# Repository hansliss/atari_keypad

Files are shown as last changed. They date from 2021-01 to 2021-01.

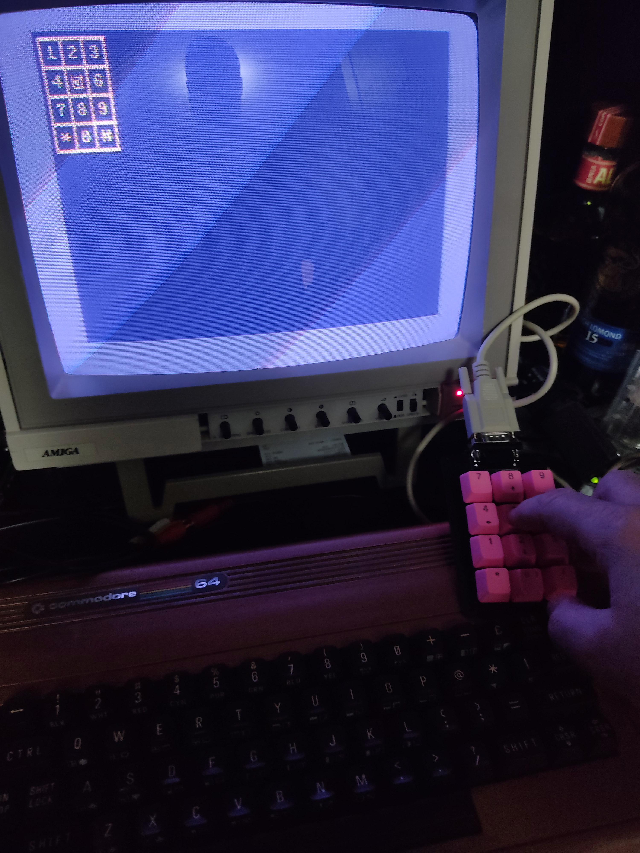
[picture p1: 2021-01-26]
2021-01-25 19.21.43.jpg

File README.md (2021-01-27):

# atari_keypad

A 12-key keypad for the joystick port, based on the Atari 2600 keypad

keypad

The keypad uses Kailh sockets for Cherry MX-compatible keyswitches,
and is meant to be used with a 3d-printed box, including a faceplate
to keep the switches in place. This box has not been designed yet.

keypad bottom

The keypad has anti-ghosting diodes on all keys. There are three
pull-up resistors, one for each column. The original keypad only
included the first two resistors, and as far as I know, the third
one is not needed.

The design includes a PCB-mounted DB-9 female connector. You can use
this with a straight, fully connected DB-9 male-to-female cable to
connect the keypad to a computer or console, or you can just solder
cables to the solder pads if you prefer that.

keypad and VIC

Included is also VIC-20 code for scanning the keypad. It includes
full N-key rollover and produces two bytes of bits, one bit for each
key. Debouncing is done by delaying keypress events until they have
been seen by at least two scanning cycles.

There is a second machine code program that calls the poller and then
"unpacks" the bit fields into a series of individual bytes, one for
each key. This is because BASIC turns out to be breathtakingly slow
at this kind of bit-mangling.

There are two BASIC programs, one that uses just the main subroutine
and does the bit unpacking itself, and another on that uses the "reorg"
subroutine to to get unpacked bytes. The second one is a little bit
faster.

Finally, there is a machine code version of the BASIC code, which
better demonstrates the keypad at full speed.

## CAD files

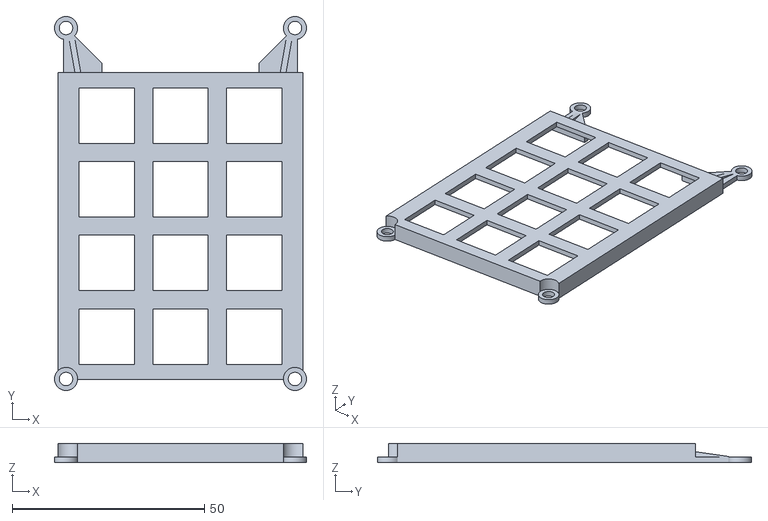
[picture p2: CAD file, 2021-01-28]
faceplate.stl
65.5 x 97.2 x 5.00

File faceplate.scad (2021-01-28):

$fn=256;

switchHoleWidth=14.4;
switchHoleDepth=14.4;
plateThickness=1.5;
facePlateTop=5;

switchesX = 3;
switchesY = 4;

switchDistX=19.15;
switchDistY=19.15;

switchOuterMargin=4;

holeDistXFromSwitchCenter = 9.85;
bottomHoleDistYFromSwitchCenter = 11;
holeYDistance=91.2;

// The keys are, sadly, not exactly centered, but this design is fixed now so we'll compensate instead.
holeRightXPos = 59.5/2; //((switchesX - 1) / 2) * switchDistX + holeDistXFromSwitchCenter;
holeLeftXPos = -holeRightXPos - 0.43;
bottomHoleYPos = -(((switchesY - 1) / 2) * switchDistY + bottomHoleDistYFromSwitchCenter);
topHoleYPos = bottomHoleYPos + holeYDistance;

topEdgeGap=36;

holeDia=3.5;
holeOuterDia=6;

facePlateWidth = (switchesX - 1) * switchDistX + switchHoleWidth + 2 * switchOuterMargin;
facePlateDepth = (switchesY - 1) * switchDistY + switchHoleDepth + 2 * switchOuterMargin;

topEdgePartWidth=(facePlateWidth - topEdgeGap) / 2;

topSparWidth=10;
topSparDepth=holeYDistance - facePlateDepth - holeDia/2;

difference() {
    union() {
        translate([0, 0, facePlateTop - plateThickness/2])
            difference() {
                cube([facePlateWidth, facePlateDepth, plateThickness], center=true);
                union() {
                    for (x = [0 : switchesX - 1]) {
                        for (y = [0 : switchesY - 1]) {
                            translate([x * switchDistX + switchHoleWidth/2 - facePlateWidth/2 + switchOuterMargin,
                                       y * switchDistY + switchHoleDepth/2 - facePlateDepth/2 + switchOuterMargin, 0])
                                cube([switchHoleWidth, switchHoleDepth, plateThickness + 0.02], center=true);
                        }
                    }
                }
            }
        intersection() {
            translate([0, 0, facePlateTop/2])
                cube([facePlateWidth, facePlateDepth, facePlateTop], center=true);
            union() {
                translate([holeLeftXPos, bottomHoleYPos, 0])
                    cylinder(r=holeOuterDia/2 + plateThickness, h=facePlateTop);
                translate([holeRightXPos, bottomHoleYPos, 0])
                    cylinder(r=holeOuterDia/2 + plateThickness, h=facePlateTop);
            }
        }
        translate([0, -(facePlateDepth/2 - plateThickness/2), facePlateTop/2])
            cube([facePlateWidth, plateThickness, facePlateTop], center = true);
        translate([-(facePlateWidth/2 + plateThickness/2), 0, facePlateTop/2])
            cube([plateThickness, facePlateDepth, facePlateTop], center = true);
        translate([(facePlateWidth/2 + plateThickness/2), 0, facePlateTop/2])
            cube([plateThickness, facePlateDepth, facePlateTop], center = true);
        translate([(facePlateWidth/2 - topEdgePartWidth/2), facePlateDepth/2 - plateThickness/2, facePlateTop/2])
            cube([topEdgePartWidth, plateThickness, facePlateTop], center=true);
        translate([-(facePlateWidth/2 - topEdgePartWidth/2), facePlateDepth/2 - plateThickness/2, facePlateTop/2])
            cube([topEdgePartWidth, plateThickness, facePlateTop], center=true);
        translate([(facePlateWidth/2 - topSparWidth/2), facePlateDepth/2 + topSparDepth/2, plateThickness/2])
            union() {
                difference() {
                    cube([topSparWidth, topSparDepth, plateThickness], center=true);
                    translate([-(topSparDepth*0.71 + holeDia), topSparDepth*0.61, 0])
                        rotate([0, 0, 45])
                            cube([topSparDepth*2, topSparDepth*2, plateThickness + 0.02], center=true);
                }
                translate([2, -1, plateThickness/2])
                    rotate([-8, 0, -10])
                        cube([plateThickness, topSparDepth, plateThickness], center=true);
            }
        translate([-(facePlateWidth/2 - topSparWidth/2), facePlateDepth/2 + topSparDepth/2, plateThickness/2])
            union() {
                difference() {
                    cube([topSparWidth, topSparDepth, plateThickness], center=true);
                    translate([topSparDepth*0.71 + holeDia, topSparDepth*0.61, 0])
                        rotate([0, 0, -45])
                            cube([topSparDepth*2, topSparDepth*2, plateThickness + 0.02], center=true);
                }
                translate([-2, -1, plateThickness/2])
                    rotate([-8, 0, 10])
                        cube([plateThickness, topSparDepth, plateThickness], center=true);
            }
    }
    union() {
        translate([holeLeftXPos, bottomHoleYPos, -0.01])
            cylinder(r = holeOuterDia/2, h = facePlateTop + 0.02);
        translate([holeRightXPos, bottomHoleYPos, -0.01])
            cylinder(r = holeOuterDia/2, h = facePlateTop + 0.02);
    }
}

translate([holeLeftXPos, bottomHoleYPos, 0])
    difference() {
        cylinder(r=holeOuterDia/2, h=plateThickness);
        translate([0, 0, -0.01])
            cylinder(r=holeDia/2, h=plateThickness + 0.02);
    }
translate([holeRightXPos, bottomHoleYPos, 0])
    difference() {
        cylinder(r=holeOuterDia/2, h=plateThickness);
        translate([0, 0, -0.01])
            cylinder(r=holeDia/2, h=plateThickness + 0.02);
    }
translate([holeLeftXPos, topHoleYPos, 0])
    difference() {
        cylinder(r=holeOuterDia/2, h=plateThickness);
        translate([0, 0, -0.01])
            cylinder(r=holeDia/2, h=plateThickness + 0.02);
    }
translate([holeRightXPos, topHoleYPos, 0])
    difference() {
        cylinder(r=holeOuterDia/2, h=plateThickness);
        translate([0, 0, -0.01])
            cylinder(r=holeDia/2, h=plateThickness + 0.02);
    }

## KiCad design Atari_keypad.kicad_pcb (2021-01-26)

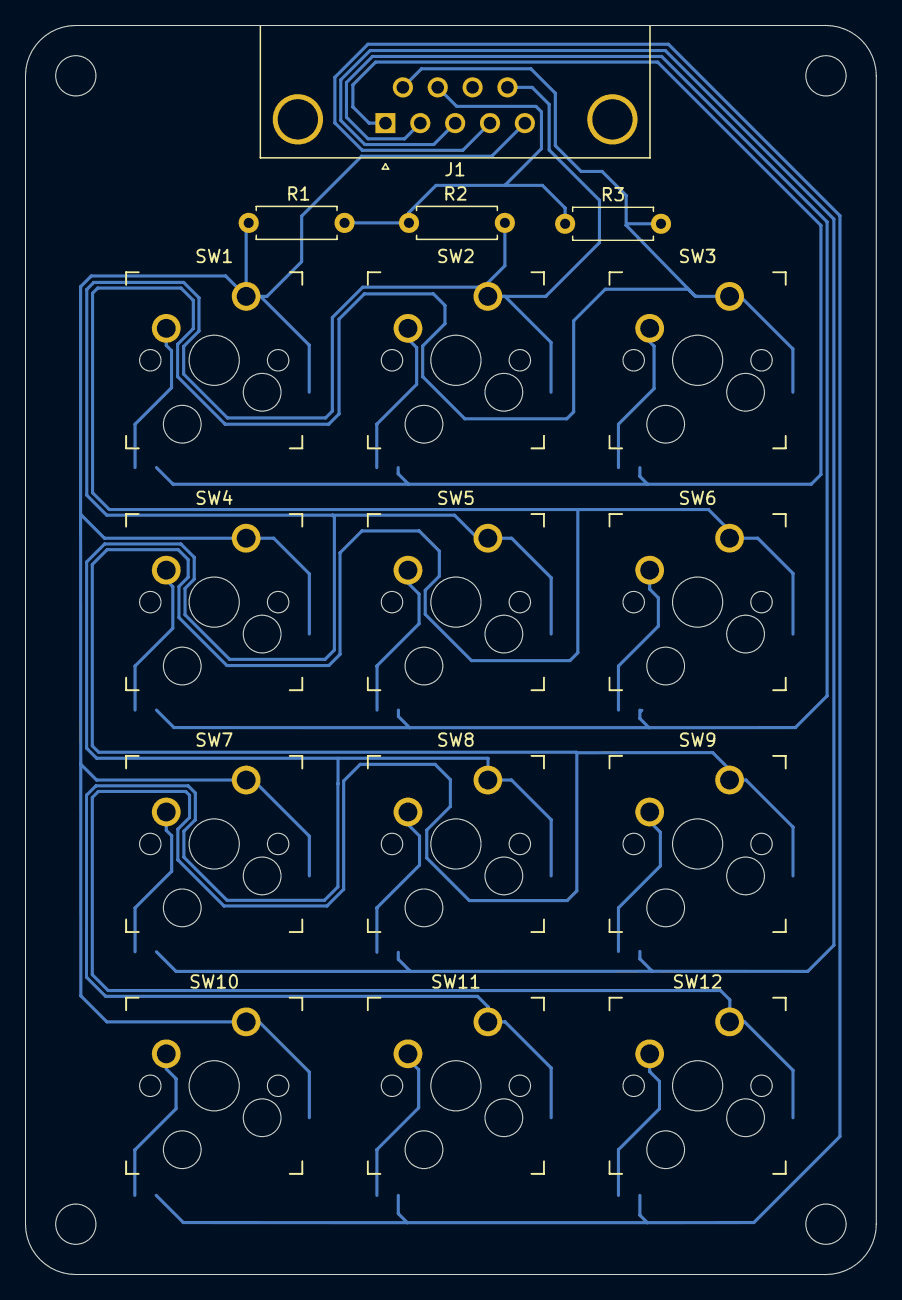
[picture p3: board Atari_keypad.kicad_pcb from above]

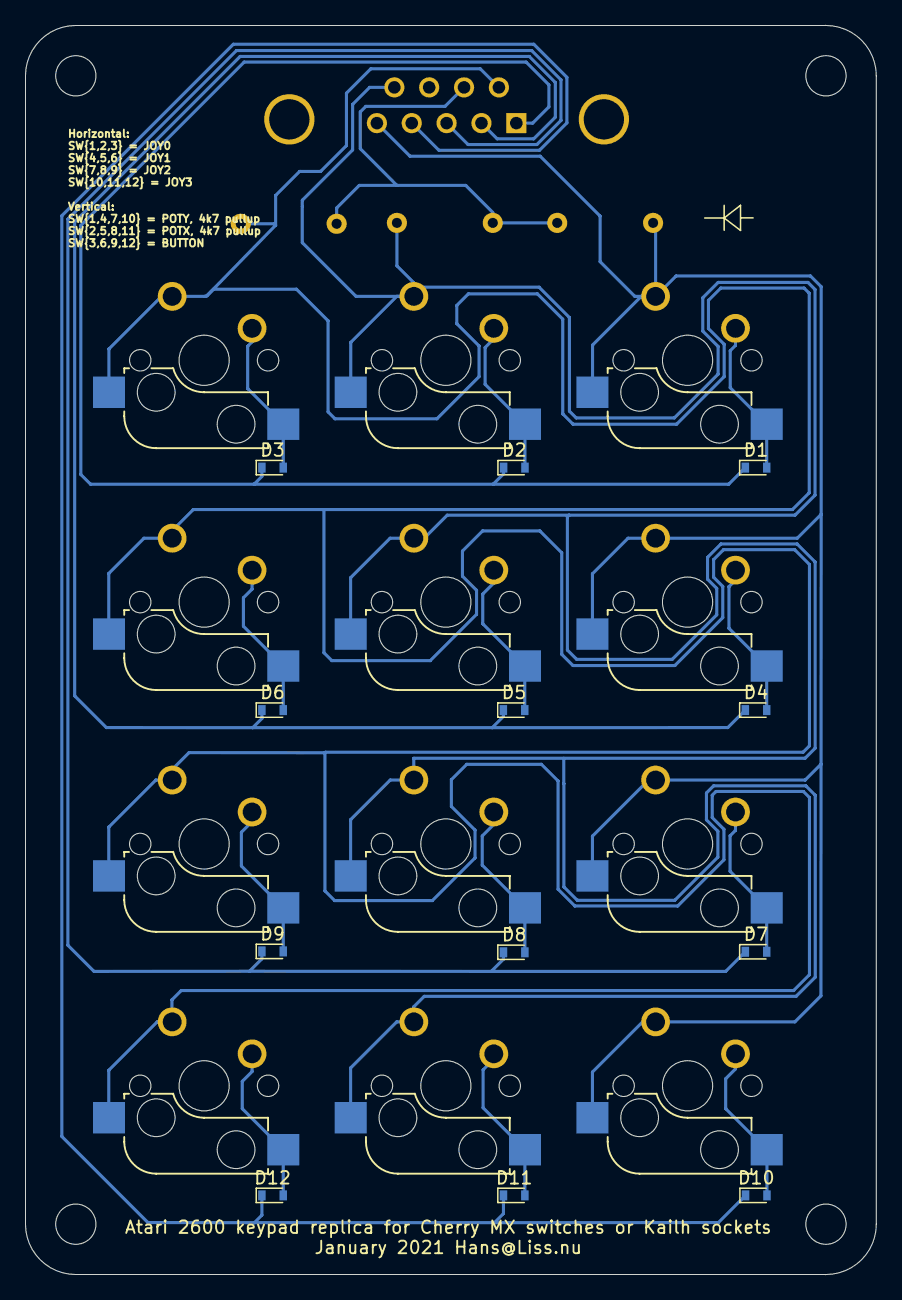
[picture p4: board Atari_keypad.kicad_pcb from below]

Board: 2 copper layers, 67.6 x 99.3 mm, 28 parts (12 on the bottom side), 20 nets.

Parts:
D1, D2, D3, D4, D5, D6, D7, D8, D9, D10, D11, D12: D; D_0603
J1: DB9_Female; DSUB-9_Female_Horizontal_P2.77x2.84mm_EdgePinOffset4.94mm_H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
R1, R2, R3: 4k7; R_Axial_DIN0207_L6.3mm_D2.5mm_P7.62mm_Horizontal
SW1: SW_1; Kailh_socket_MX_optional_compatible
SW2: SW_2; Kailh_socket_MX_optional_compatible
SW3: SW_3; Kailh_socket_MX_optional_compatible
SW4: SW_4; Kailh_socket_MX_optional_compatible
SW5: SW_5; Kailh_socket_MX_optional_compatible
SW6: SW_6; Kailh_socket_MX_optional_compatible
SW7: SW_7; Kailh_socket_MX_optional_compatible
SW8: SW_8; Kailh_socket_MX_optional_compatible
SW9: SW_9; Kailh_socket_MX_optional_compatible
SW10: SW_Star; Kailh_socket_MX_optional_compatible
SW11: SW_0; Kailh_socket_MX_optional_compatible
SW12: SW_Hash; Kailh_socket_MX_optional_compatible

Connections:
/+5V: J1.7, R1.1, R2.1, R3.1
/BUT: J1.6, R3.2, SW3.1, SW6.1, SW9.1, SW12.1
/JOY0: D1.1, D2.1, D3.1, J1.1
/JOY1: D4.1, D5.1, D6.1, J1.2
/JOY2: D7.1, D8.1, D9.1, J1.3
/JOY3: D10.1, D11.1, D12.1, J1.4
/POTX: J1.9, R2.2, SW2.1, SW5.1, SW8.1, SW11.1
/POTY: J1.5, R1.2, SW1.1, SW4.1, SW7.1, SW10.1
unnamed: D1.2, SW1.2
unnamed: D2.2, SW2.2
unnamed: D3.2, SW3.2
unnamed: D4.2, SW4.2
unnamed: D5.2, SW5.2
unnamed: D6.2, SW6.2
unnamed: D7.2, SW7.2
unnamed: D8.2, SW8.2
unnamed: D9.2, SW9.2
unnamed: D10.2, SW10.2
unnamed: D11.2, SW11.2
unnamed: D12.2, SW12.2

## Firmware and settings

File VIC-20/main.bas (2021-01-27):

!-CONST KEY1 $1A0D
!-CONST KEY2 $1A0E
!-CONST POLL $1A0F
10 PRINT"{clear}{red}";
20 PRINT"{cm a}{sh asterisk}{cm r}{sh asterisk}{cm r}{sh asterisk}{cm s}"
30 PRINT"{sh -}1{sh -}2{sh -}3{sh -}"
40 PRINT"{cm q}{sh asterisk}{sh +}{sh asterisk}{sh +}{sh asterisk}{cm w}"
50 PRINT"{sh -}4{sh -}5{sh -}6{sh -}"
60 PRINT"{cm q}{sh asterisk}{sh +}{sh asterisk}{sh +}{sh asterisk}{cm w}"
70 PRINT"{sh -}7{sh -}8{sh -}9{sh -}"
80 PRINT"{cm q}{sh asterisk}{sh +}{sh asterisk}{sh +}{sh asterisk}{cm w}"
90 PRINT"{sh -}*{sh -}0{sh -}#{sh -}"
100 PRINT"{cm z}{sh asterisk}{cm e}{sh asterisk}{cm e}{sh asterisk}{cm x}"
110 DIM P(12)
120 FOR Y=0 TO 3
130 FOR X=0 TO 2
140 P(Y*3+X+1)=7680+Y*44+X*2+23
150 NEXT
160 NEXT
170 SYS POLL
180 LK1=K1:LK2=K2:K1=PEEK(KEY1):K2=PEEK(KEY2)
190 IF LK1=K1 AND LK2=K2 THEN 170
200 FOR Y=0 TO 3
210 FOR X=0 TO 2
220 MASK=2^((Y * 3 + X) AND 7)
230 V=K1 AND MASK
240 IF ((Y AND 1) OR ((X AND 2)/2)) AND ((Y AND 2) / 2) THEN V=K2 AND MASK
250 IF V<>0 THEN POKE P(Y*3+X+1),PEEK(P(Y*3+X+1)) OR 128
260 IF V=0 THEN POKE P(Y*3+X+1),PEEK(P(Y*3+X+1)) AND 127
270 NEXT
280 NEXT
290 GOTO 170

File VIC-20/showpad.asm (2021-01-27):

; A machine code version of the keypad demo. It's snappy!

* = $1A00

SCR=$1E00

PLEN = PADEND-PAD

START
        LDY #$00
@LOOP
        LDA PAD,Y
        JSR $FFD2
        INY
        CPY #PLEN
        BNE @LOOP

READER
        JSR POLL$
        ; Initialize everything
        LDA #$00
        STA ROW
        STA COL
        STA IDX
        LDX KEY$
LOOP1
        ; SCR+Y*44+X*2+23
        LDA ROW
        ASL
        ASL
        STA RTMP
        ASL
        TAY
        ADC RTMP
        STA RTMP
        TYA
        ASL
        ASL
        ADC RTMP
        STA RTMP
        LDA COL
        ASL
        ADC RTMP
        ADC #23
        TAY
        ; If we're at exactly the ninth key
        CMP #115
        BNE FBYTE
        LDX KEY$+1
FBYTE
        TXA
        AND #$01
        BEQ KREL
        LDA SCR,Y
        ORA #$80
        STA SCR,Y
        BNE KDONE
KREL
        LDA SCR,Y
        AND #$7F
        STA SCR,Y
KDONE
        ; Shift in the next bit of the bitfield
        TXA
        LSR
        TAX

        INC COL
        LDA COL
        CMP #3
        BMI LOOP1
        LDA #0
        STA COL
        INC ROW
        LDA ROW
        CMP #4
        BMI LOOP1
        JMP READER

COL     BYTE 0
ROW     BYTE 0
IDX     BYTE 0
RTMP    BYTE 0

PAD     BYTE "{clear}{red}"
        BYTE "{cm a}{sh asterisk}{cm r}{sh asterisk}{cm r}{sh asterisk}{cm s}",$0D
        BYTE "{sh -}1{sh -}2{sh -}3{sh -}",$0D
        BYTE "{cm q}{sh asterisk}{sh +}{sh asterisk}{sh +}{sh asterisk}{cm w}",$0D
        BYTE "{sh -}4{sh -}5{sh -}6{sh -}",$0D
        BYTE "{cm q}{sh asterisk}{sh +}{sh asterisk}{sh +}{sh asterisk}{cm w}",$0D
        BYTE "{sh -}7{sh -}8{sh -}9{sh -}",$0D
        BYTE "{cm q}{sh asterisk}{sh +}{sh asterisk}{sh +}{sh asterisk}{cm w}",$0D
        BYTE "{sh -}*{sh -}0{sh -}#{sh -}",$0D
        BYTE "{cm z}{sh asterisk}{cm e}{sh asterisk}{cm e}{sh asterisk}{cm x}"
PADEND

Incasm "poller.asm"

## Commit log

2021-01-26 Initial import
    [Atari_keypad.kicad_pcb, Atari_keypad.sch]
2021-01-26 Added comments to assembler code
2021-01-27 Restructured the poller code, so I/O ports are restored, and interrupts enabled, earlier. Restructured the project, extracting the poller code into its own file to be included into the others. Change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
2021-01-28 Added a 3d-printable faceplate to stabilize the keyswitches
    [faceplate.scad, faceplate.stl]
2021-01-28 Minor adjustment of left-side holes, to accommodate a slight error in the positioning of the keys in relation to the PCB.
    [faceplate.scad]
